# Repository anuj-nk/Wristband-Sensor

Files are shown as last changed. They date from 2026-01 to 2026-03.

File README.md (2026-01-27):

# ThrowSense  
*A wearable system that measures throw speed and estimates throw distance, visualized through a physical stepper-motor gauge and an OLED display.*

---

## Project Overview

ThrowSense is a two-device interactive system consisting of a wearable sensing unit and a handheld or desk-mounted display unit. The wearable tracks the motion of a throw using inertial sensors and computes an estimated throw speed and distance. The display device presents this information using a physical needle gauge driven by a stepper motor, along with an OLED screen for numeric readouts and mode selection.

The system is designed to provide intuitive, glanceable feedback for different throwing contexts (e.g., football, baseball), emphasizing physical interaction and real-world sensing over screen-only visualization.

### General Physical Sketch


---

## Sensing Device — Wearable Motion Tracker

### Device Overview

The sensing device is a wrist- or forearm-mounted wearable that captures high-frequency motion data during a throwing action. It detects when a throw occurs, estimates release velocity, and performs lightweight DSP and physics-based calculations before transmitting results to the display device.

### Hardware Components

- **Processor:** ESP32-C3
- **IMU Sensor:** MPU-6050  
  - 3-axis accelerometer  
  - 3-axis gyroscope  
- **Power:**  
  - 3.7V LiPo battery  

### Part Numbers

- ESP32-C3  
- MPU-6050

### How It Works

1. The MPU-6050 continuously samples acceleration and angular velocity.
2. Motion data is filtered and analyzed in real time to detect a throwing event.
3. Peak angular velocity and acceleration are extracted during the throw.
4. Release speed is estimated from IMU data.
5. A simplified physics-based model estimates throw distance based on:
   - selected object type (e.g., football, baseball)
   - assumed release angle
   - object-specific parameters (mass, drag heuristic).
6. Final computed values are transmitted to the display device.

### Sensor Device Sketch


---

## Display Device — Physical Gauge + OLED Interface

### Device Overview

The display device is a handheld or desk-mounted physical interface that presents throw data in both analog and digital forms. A stepper-motor-driven needle provides an immediate visual indication of throw speed, while an OLED display shows numeric values and the selected throw mode. A button allows the user to cycle through object types before throwing.

### Hardware Components

- **Processor:** ESP32-C3
- **Stepper Motor:** 28BYJ-48
- **Stepper Driver:** ULN2003
- **Display:** 0.96" I2C OLED (SSD1306)
- **User Input:** Tactile push button
- **Indicator:** Status LED
- **Power:** Wall power or battery (TBD)

### Part Numbers

- ESP32-C3  
- 28BYJ-48 Stepper Motor  
- ULN2003 Driver Board  
- SSD1306 OLED Display  

### How It Works

1. The display device receives processed throw data from the sensing device.
2. The stepper motor rotates the needle to a mapped angle corresponding to throw speed.
3. The OLED displays:
   - selected throw mode (e.g., football, baseball)
   - measured throw speed
   - estimated throw distance
4. The user presses a button to cycle through throw modes.
5. Mode changes are sent back to the sensing device to update calculation parameters.
6. The status LED indicates system state:
   - **Ready:** system prepared to detect a throw  
   - **Throwing:** motion detected  
   - **Processing:** calculations in progress  

### Display Device Sketch


---

## Device Communication & System Architecture

### Device Communication

- **Communication medium:** To be determined (wired or wireless)
- **Topology:** Sensing device → Display device
- The sensing device performs all DSP and physics calculations.
- The display device focuses on visualization and user interaction.

### System Diagram — High-Level Communication
SystemArchitecture

### System Diagram — Data Flow
514-Schematic_page-0001

**Data Flow Explanation:**

1. Raw IMU data is captured on the sensing device.
2. DSP techniques (filtering, thresholding, peak detection) identify a throw.
3. A physics-based model estimates speed and distance.
4. Final metrics are transmitted to the display device.
5. The display device maps speed to motor position and updates the OLED and LED indicators.

## Datasheets

All datasheets are included in the `/datasheets` directory, including:

- ESP32-C3 datasheet  
- MPU-6050 datasheet  
- 28BYJ-48 stepper motor datasheet  
- ULN2003 driver datasheet  
- SSD1306 OLED datasheet

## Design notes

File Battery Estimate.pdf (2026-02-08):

System Parameters (defined by hardware) | Profiles (usage of each component mode - defined by software and usage)
form the datasheets
"off" | "sensing" | "interactive"
Processor
Active | 76 mW | 0% | 1% | 20%

This is for my Sensing Device which is using battery and not my Display which is not using battery
Idle | 53 mW | 0% | 4% | 10%
Deep Sleep | 0 mW | 100% | 95% | 70%

Values are rounded, but I
changed template values
although it still shows 0

LED

On | 0 mW | 0% | 0% | 0%

No LED in sensing device, based on this battery analysis maybe I can include one

Sensor
On | 13 mW | 0% | 0% | 100%
Idle | 2 mW | 0% | 100% | 0%
Off | 0 mW | 100% | 0% | 0%

Display
On | 0 mW | 0% | 0% | 0%
Off (leakage) | 0 mW | 0% | 0% | 0% No Display for Sensing Device

Radio

Data Rate | 13,000 bps | 0% | 0% | 0%

There is a DPU on the MPU6050 which does all the calculations

and would reduce amount of
dataneeded to be sent, but for
now assuming you send all data
to other microcontroller | Total power in profile (mw) | Maximum Time
Standby Power | 1 mW | 0% | 100% | 95% | "off" | 0.4455 mW | 1931.0 hours
TX Power | 65 mW | 0% | 0% | 3% | "sensing" | 5.99155 mW | 143.6 hours
RX Power | 40 mW | 0% | 0% | 2% | "interactive" | 37.3303 mW | 23.0 hours
14 | 9 | 1 hours/day typical usage | Effective Battery Capacity
Battery | | | | | | 860.25 mW*h
Capacity | 250 mAh
Nominal Voltage | 4 V | | | | Days of Use | 8.82 days
Regulator Efficiency | 93% | | | | Hours of Use | 211.77 hours

REFLECTIONS : WHAT DID YOU LEARN FROM ANALYZING YOUR POWER. TALK ABOUT SOME POTENTIAL TRADEOFFS.
Based on the power analysis, I determined the days of use metric by modeling a typical day across three usage profiles: off, sensing, and interactive, and weighting each by the expected hours per day. This approach captures realistic behavior rather than relying on worst case or peak power scenarios. Using this model, a 210 mAh battery provides approximately 7.4 days of operation, while even a much smaller 50 mAh battery still supports about 1.7 days of typical use.

Given these results, an optimal battery size for the wristband is likely in the 200 to 300 mAh range. This size provides ample margin for variability in usage, battery aging, and inefficiencies, while remaining small and comfortable for a wearable form factor. The analysis also shows that the system could function for a full day with a significantly smaller battery if needed.

Several tradeoffs could further improve the user experience. From a software perspective, minimizing radio usage by computing velocity on-device and transmitting only compact result packets keeps power consumption low without reducing functionality. From a hardware perspective, aggressively using sensor low power modes and processor sleep states improves battery life at the cost of slightly increased latency and implementation effort. Increasing responsiveness or streaming more data would improve immediacy and fidelity but would require higher power draw, a larger battery, or additional development complexity.

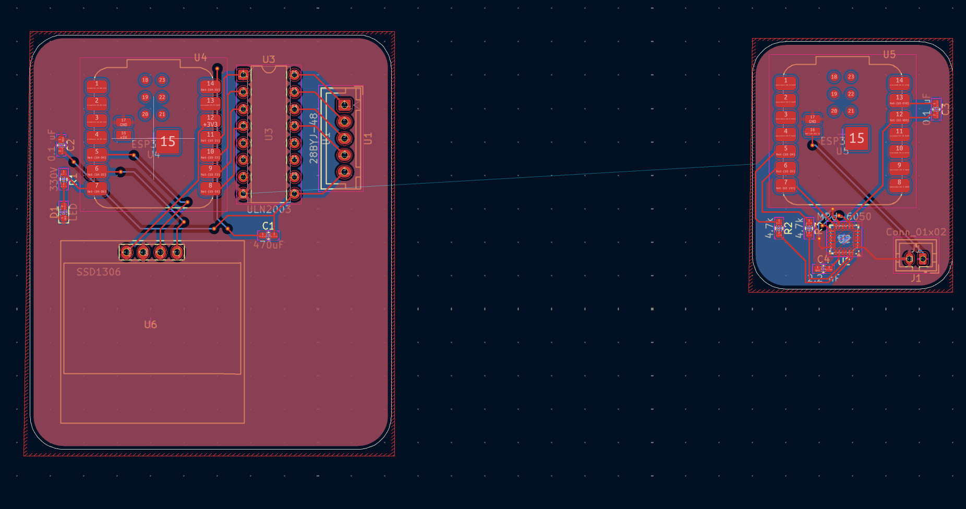
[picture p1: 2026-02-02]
TECHIN514_w26_project_PCB/514-Schematic-FinalProject/Screenshot 2026-02-02 at 3.05.42 PM.png

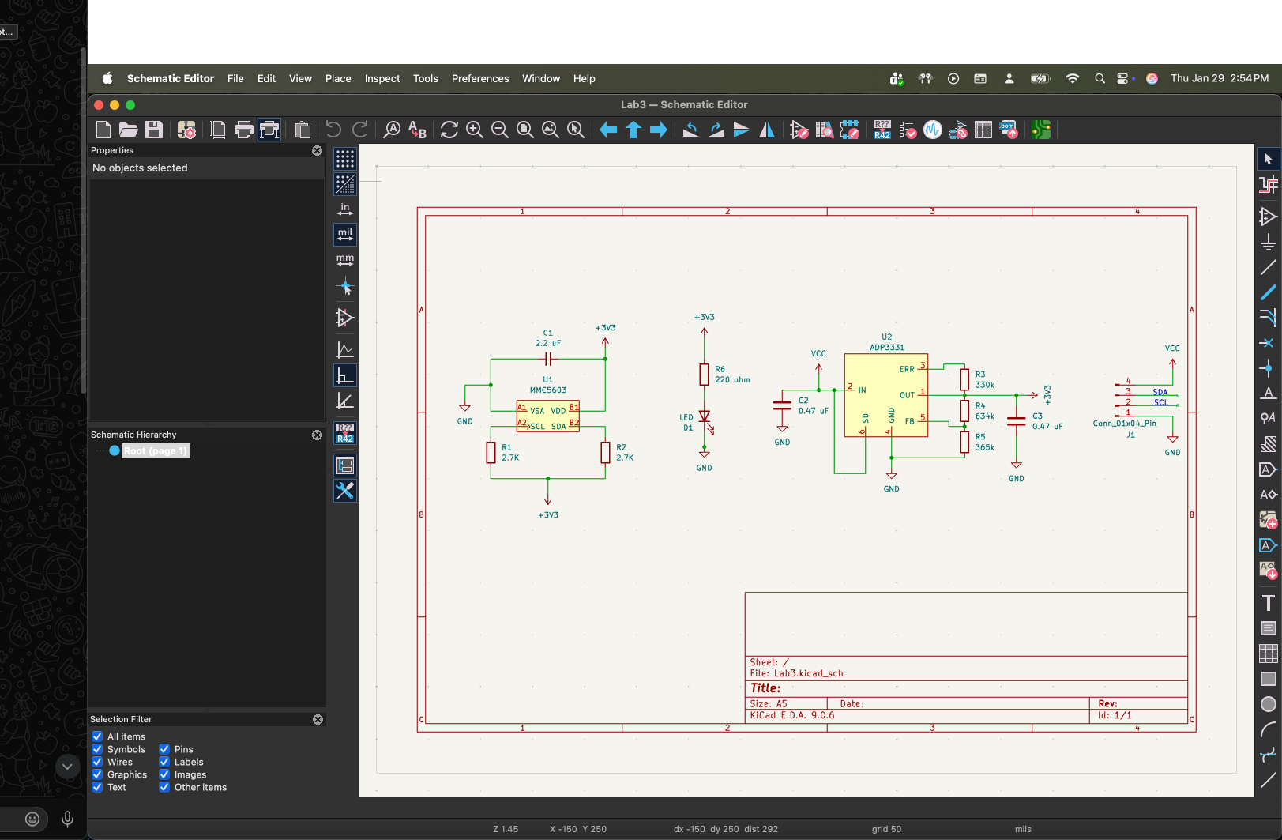
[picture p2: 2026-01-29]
TECHIN514_w26_project_PCB/Lab3/SchematicDiagram.png

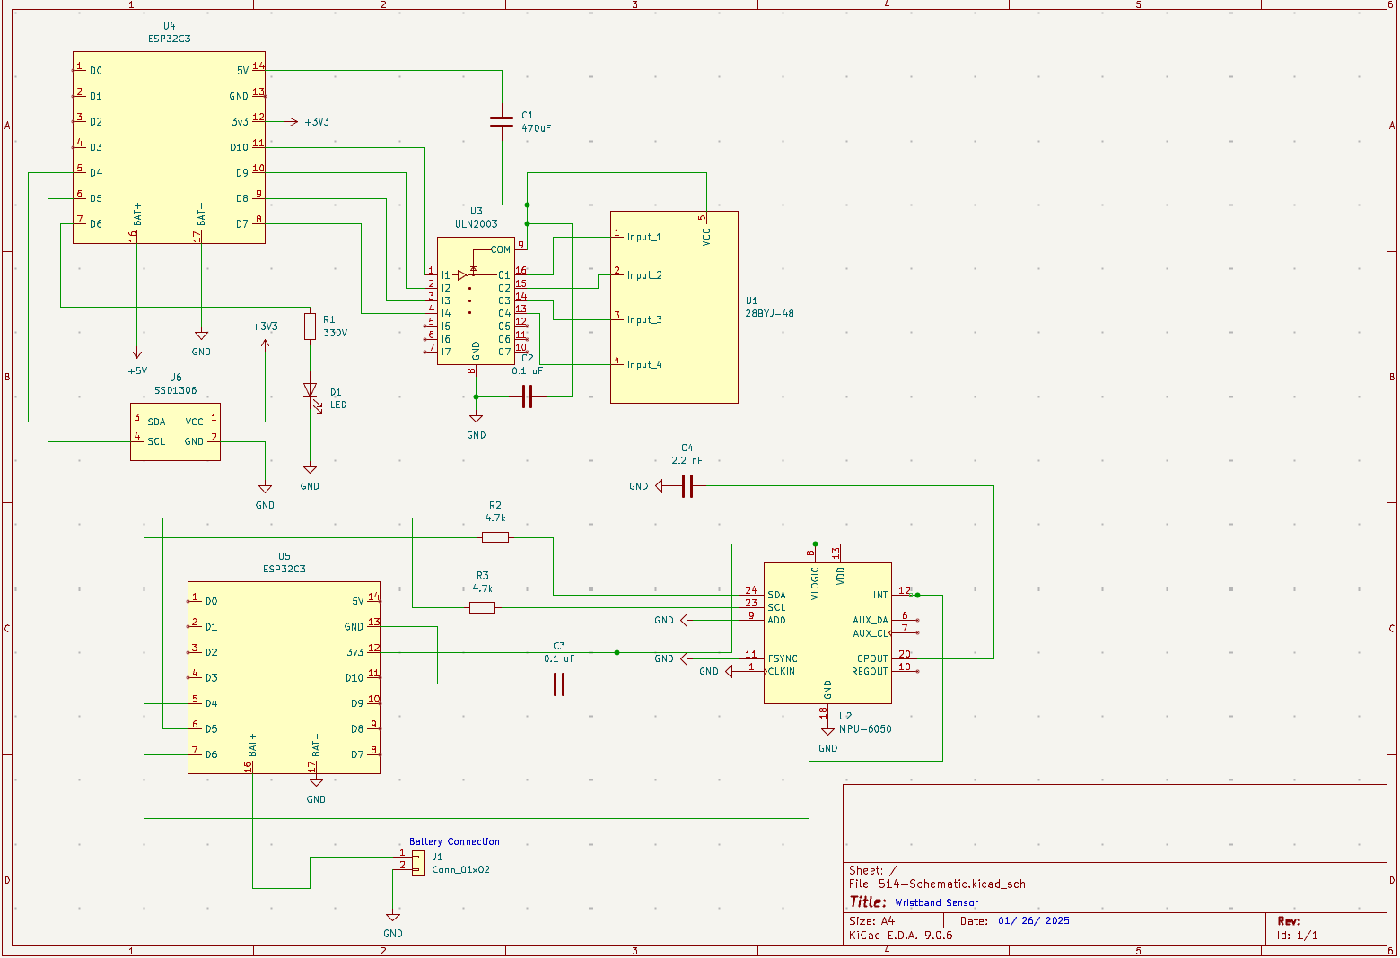
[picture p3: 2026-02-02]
TECHIN514_w26_project_PCB/514-Schematic-FinalProject/Screenshot 2026-02-02 at 3.06.13 PM.png

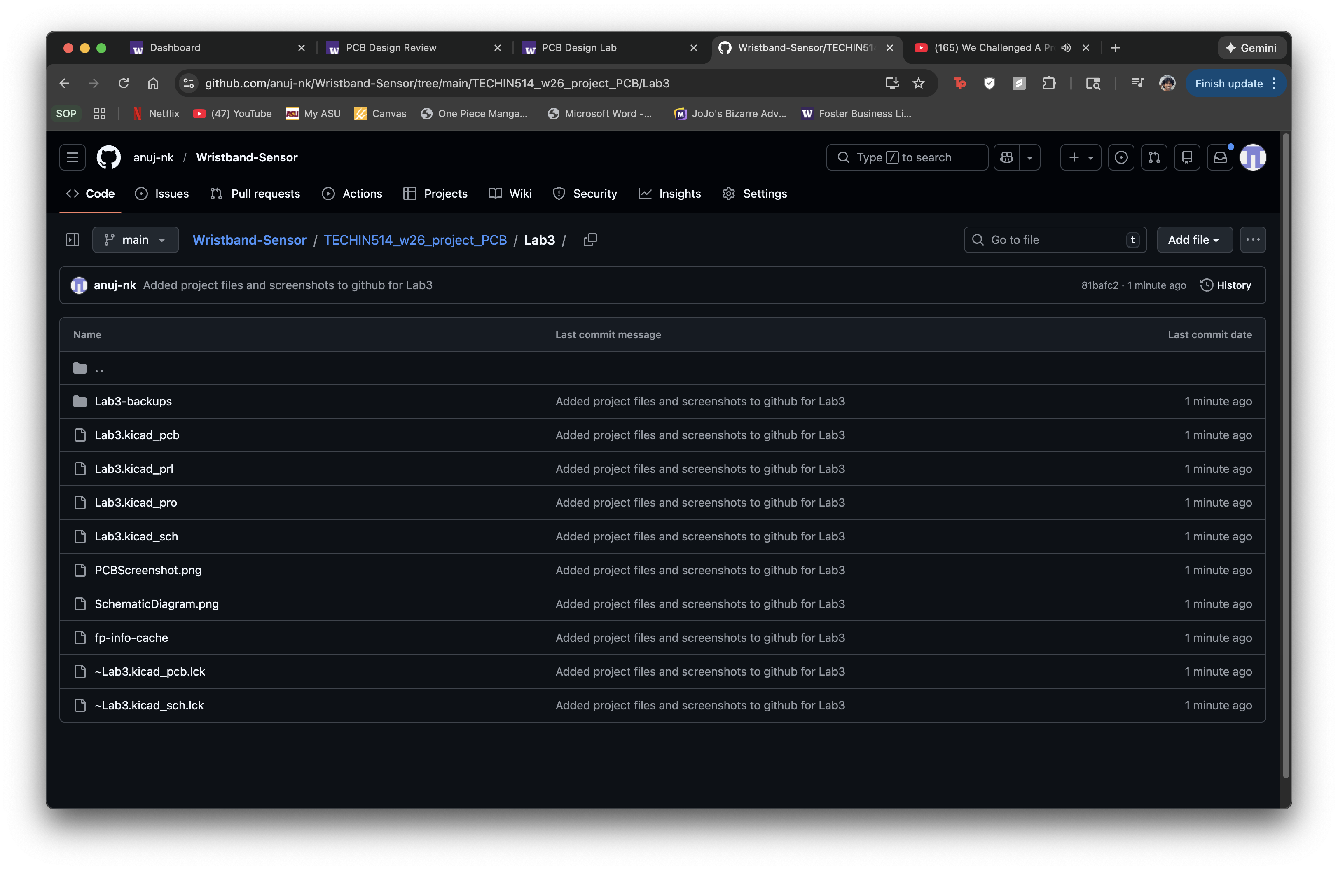
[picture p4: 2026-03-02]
TECHIN514_w26_project_PCB/Lab3/Screenshot 2026-01-29 at 2.56.57 PM.png

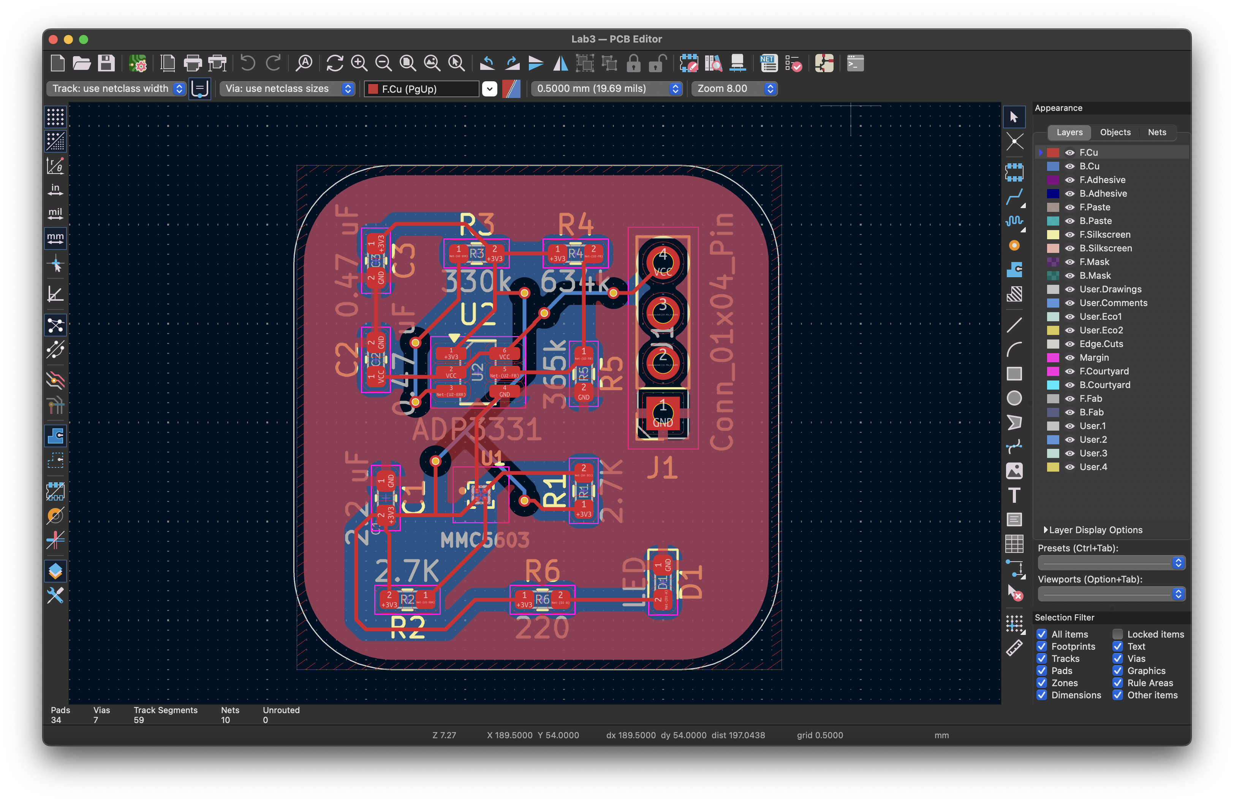
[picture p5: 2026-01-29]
TECHIN514_w26_project_PCB/Lab3/PCBScreenshot.png

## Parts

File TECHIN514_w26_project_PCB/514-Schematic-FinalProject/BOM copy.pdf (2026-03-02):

### BOM

Reference | Qty | Value | DNP | Exclude from BOM | Exclude from Board | Footprint | Datasheet
C1 | 1 | 470uF | | | | Capacitor_SMD:C_0603_1608Metric_Pad1.08x0.95mm_HandSolder | ~
C2,C3 | 2 | 0.1 uF | | | | Capacitor_SMD:C_0603_1608Metric_Pad1.08x0.95mm_HandSolder | ~
C4 | 1 | 2.2 nF | | | | Capacitor_SMD:C_0603_1608Metric_Pad1.08x0.95mm_HandSolder | ~
D1 | 1 | LED - Red | | | | LED_SMD:LED_0603_1608Metric_Pad1.05x0.95mm_HandSolder | ~
J1 | 1 | Conn_01x02 | | | | Connector_JST:JST_PH_B2B-PH-K_1x02_P2.00mm_Vertical | ~
R1 | 1 | 330Ω | | | | Resistor_SMD:R_0603_1608Metric_Pad0.98x0.95mm_HandSolder | ~
R2,R3 | 2 | 4.7k | | | | Resistor_SMD:R_0603_1608Metric_Pad0.98x0.95mm_HandSolder | ~
U1 | 1 | 28BYJ-48 | Connector_JST:JST_XH_B5B-XH-A_1x05_P2.50mm_Vertical | https://www.mouser.com/datasheet/2/758/stepd-01-data-sheet-1143075.pdf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
U2 | 1 | MPU-6050 | Sensor_Motion:InvenSense_QFN-24_4x4mm_P0.5mm | https://invensense.tdk.com/wp-content/uploads/2015/02/MPU-6000-Datasheet1.pdf
U3 | 1 | ULN2003 | Package_DIP:DIP-16_W7.62mm | http://www.ti.com/lit/ds/symlink/uln2003a.pdf
U4,U5 | 2 | ESP32C3 | RF_Module:MCU_Seeed_ESP32C3 | https://documentation.espressif.com/esp32-c3_datasheet_en.pdf
U6 | 1 | SSD1306 | Footprints:128x64OLED | https://cdn-shop.adafruit.com/datasheets/SSD1306.pdf

1

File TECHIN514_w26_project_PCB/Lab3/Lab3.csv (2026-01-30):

Reference | Qty | Value | DNP | Exclude from BOM | Exclude from Board | Footprint | Datasheet
C1 | 1 | 2.2 uF |  |  |  | Capacitor_SMD:C_0603_1608Metric_Pad1.08x0.95mm_HandSolder | ~
C2,C3 | 2 | 0.47 uF |  |  |  | Capacitor_SMD:C_0603_1608Metric_Pad1.08x0.95mm_HandSolder | ~
D1 | 1 | LED |  |  |  | LED_SMD:LED_0603_1608Metric_Pad1.05x0.95mm_HandSolder | ~
J1 | 1 | Conn_01x04_Pin |  |  |  | Connector_PinSocket_2.54mm:PinSocket_1x04_P2.54mm_Vertical | ~
R1,R2 | 2 | 2.7K |  |  |  | Resistor_SMD:R_0603_1608Metric_Pad0.98x0.95mm_HandSolder | ~
R3 | 1 | 330k |  |  |  | Resistor_SMD:R_0603_1608Metric_Pad0.98x0.95mm_HandSolder | ~
R4 | 1 | 634k |  |  |  | Resistor_SMD:R_0603_1608Metric_Pad0.98x0.95mm_HandSolder | ~
R5 | 1 | 365k |  |  |  | Resistor_SMD:R_0603_1608Metric_Pad0.98x0.95mm_HandSolder | ~
R6 | 1 | 220 ohm |  |  |  | Resistor_SMD:R_0603_1608Metric_Pad0.98x0.95mm_HandSolder | ~
U1 | 1 | MMC5603 |  |  |  | MMC5603NJ:XDCR_MMC5603NJ
U2 | 1 | ADP3331 |  |  |  | Package_TO_SOT_SMD:SOT-23-6_Handsoldering

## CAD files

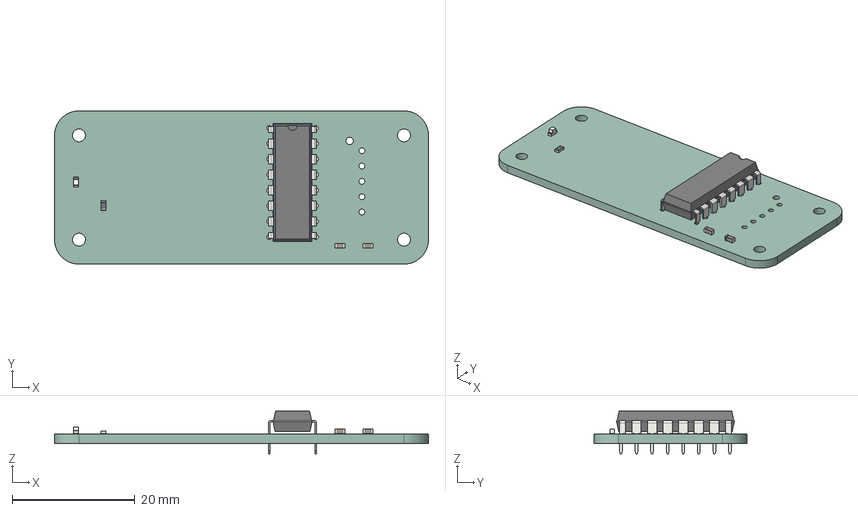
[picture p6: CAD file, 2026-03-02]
TECHIN514_w26_project_PCB/514-Schematic-FinalProject/514-Schematic-D.step
61.0 x 25.0 x 6.98 mm
LED_0603_1608Metric
R_0603_1608Metric
C_0603_1608Metric x 2
DIP-16_W7.62mm
514-Schematic-D_PCB

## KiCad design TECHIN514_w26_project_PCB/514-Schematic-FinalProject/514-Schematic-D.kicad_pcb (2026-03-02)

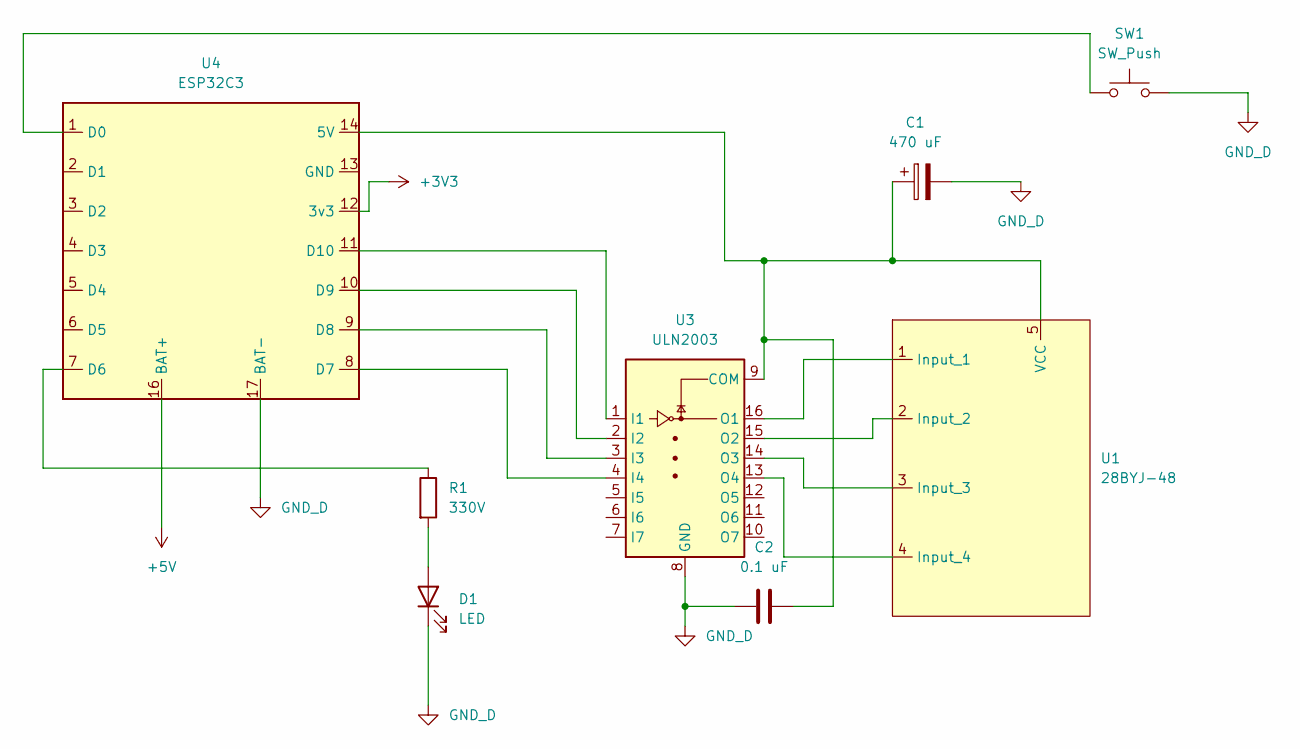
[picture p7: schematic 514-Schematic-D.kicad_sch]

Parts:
C1: 470 uF; C_0603_1608Metric_Pad1.08x0.95mm_HandSolder
C2: 0.1 uF; C_0603_1608Metric_Pad1.08x0.95mm_HandSolder
D1: LED; LED_0603_1608Metric_Pad1.05x0.95mm_HandSolder
R1: 330V; R_0603_1608Metric_Pad0.98x0.95mm_HandSolder
SW1: SW_Push; SW_PUSH_6mm
U1: 28BYJ-48; JST_XH_B5B-XH-AM_1x05_P2.50mm_Vertical
U3: ULN2003; DIP-16_W7.62mm
U4: ESP32C3; MCU_Seeed_ESP32C3

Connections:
+3V3: U4.12 (3v3)
+5V: U4.16 (BAT+)
GND_D: C1.2, C2.1, D1.1 (K), SW1.2, U3.8 (GND), U4.17 (BAT-)
unnamed: D1.2 (A), R1.2
unnamed: U1.1 (Input_1), U3.16 (O1)
unnamed: U1.2 (Input_2), U3.15 (O2)
unnamed: U1.3 (Input_3), U3.14 (O3)
unnamed: U1.4 (Input_4), U3.13 (O4)
unnamed: C1.1, C2.2, U1.5 (VCC), U3.9 (COM), U4.14 (5V)
unnamed: U3.1 (I1), U4.11 (D10)
unnamed: U3.2 (I2), U4.10 (D9)
unnamed: U3.3 (I3), U4.9 (D8)
unnamed: U3.4 (I4), U4.8 (D7)
unnamed: SW1.1, U4.1 (D0)
unnamed: R1.1, U4.7 (D6)

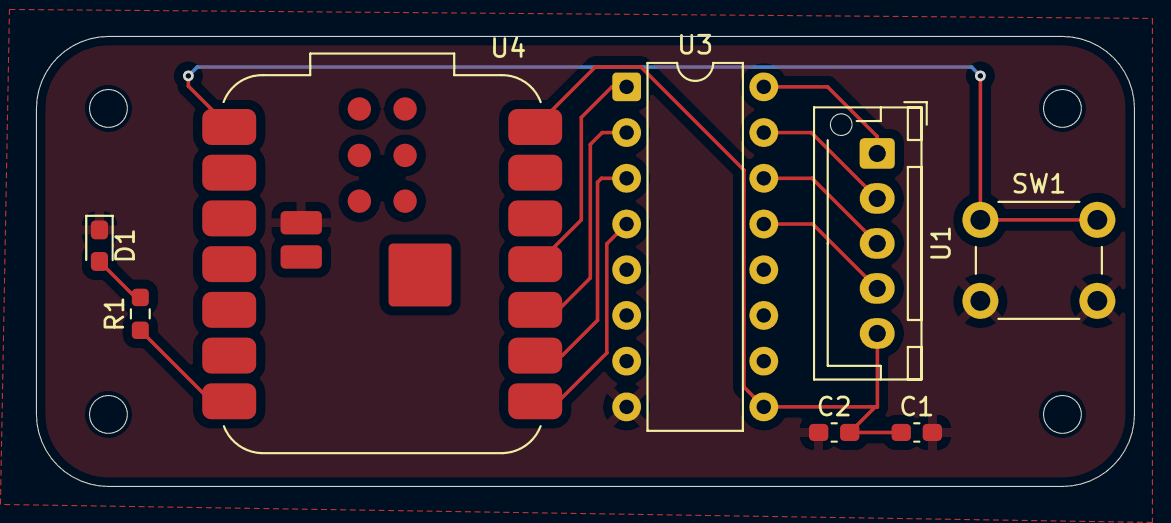
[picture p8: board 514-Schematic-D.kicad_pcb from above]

Board: 2 copper layers, 61.0 x 25.0 mm, 8 parts (0 on the bottom side), 13 nets.

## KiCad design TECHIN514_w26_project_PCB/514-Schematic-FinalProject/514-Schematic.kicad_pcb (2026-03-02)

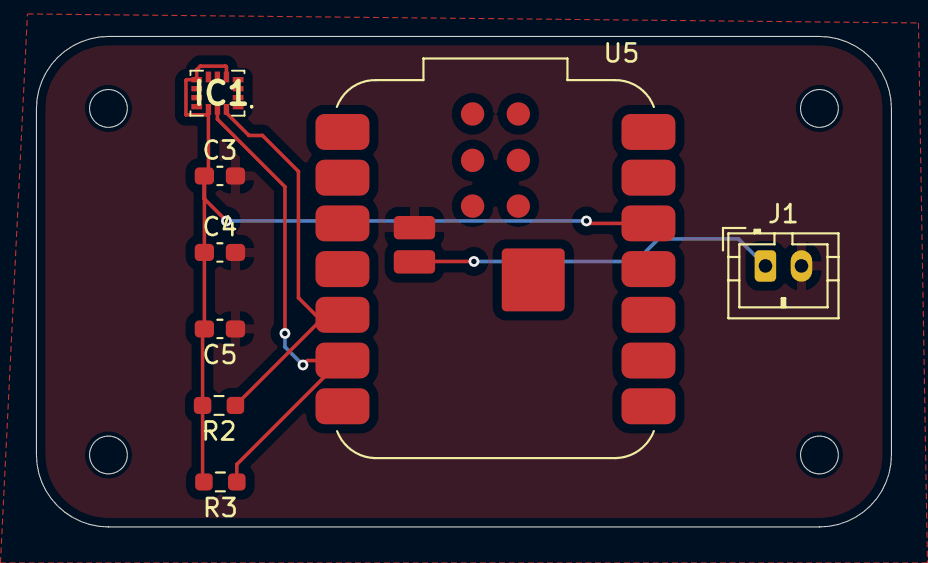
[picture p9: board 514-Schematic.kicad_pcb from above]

Board: 2 copper layers, 47.5 x 27.2 mm, 8 parts (0 on the bottom side), 5 nets.

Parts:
C3: 0.1 uF; C_0603_1608Metric_Pad1.08x0.95mm_HandSolder
C4: 2.2 uF; C_0603_1608Metric_Pad1.08x0.95mm_HandSolder
C5: 10 nF; C_0603_1608Metric_Pad1.08x0.95mm_HandSolder
IC1: ICM-42670-P; ICM42670P
J1: Conn_01x02; JST_PH_B2B-PH-K_1x02_P2.00mm_Vertical
R2, R3: 10 kΩ; R_0603_1608Metric_Pad0.98x0.95mm_HandSolder
U5: ESP32C3; MCU_Seeed_ESP32C3

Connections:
GND: C3.2, C4.2, C5.1, IC1.1 (AP_SDO_/_AP_AD0), IC1.6 (GND), IC1.7 (FSYNC), J1.2, U5.17 (BAT-)
unnamed: C3.1, C4.1, C5.2, IC1.5 (VDDIO), IC1.8 (VDD), IC1.12 (AP_CS), R2.2, R3.2, U5.12 (3v3)
unnamed: IC1.13 (AP_SCL_/_AP_SCLK), R3.1, U5.6 (D5)
unnamed: IC1.14 (AP_SDA_/_AP_SDIO_/_AP_SDI), R2.1, U5.5 (D4)
unnamed: J1.1, U5.16 (BAT+)

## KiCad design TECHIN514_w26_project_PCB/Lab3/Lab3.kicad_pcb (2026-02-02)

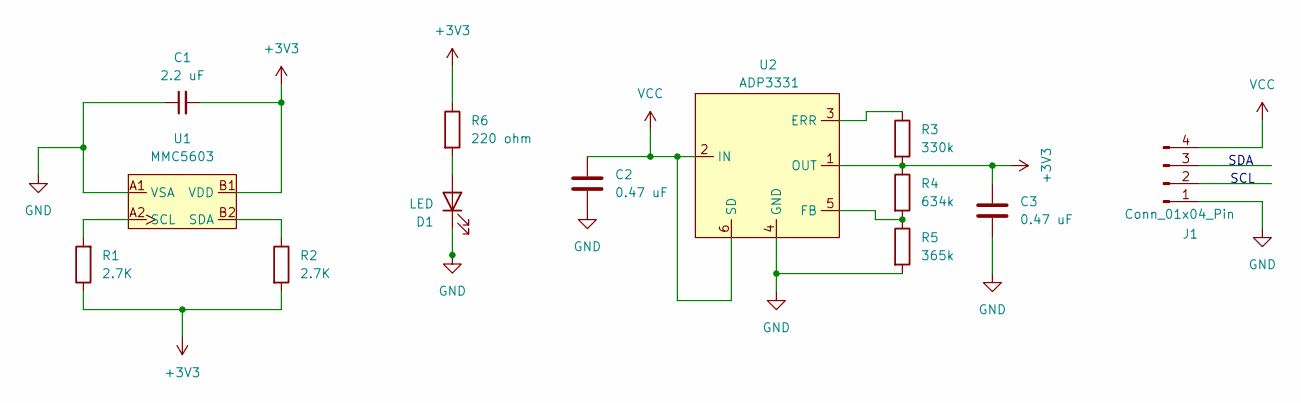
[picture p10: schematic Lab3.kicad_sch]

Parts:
C1: 2.2 uF; C_0603_1608Metric_Pad1.08x0.95mm_HandSolder
C2, C3: 0.47 uF; C_0603_1608Metric_Pad1.08x0.95mm_HandSolder
D1: LED; LED_0603_1608Metric_Pad1.05x0.95mm_HandSolder
J1: Conn_01x04_Pin; PinSocket_1x04_P2.54mm_Vertical
R1, R2: 2.7K; R_0603_1608Metric_Pad0.98x0.95mm_HandSolder
R3: 330k; R_0603_1608Metric_Pad0.98x0.95mm_HandSolder
R4: 634k; R_0603_1608Metric_Pad0.98x0.95mm_HandSolder
R5: 365k; R_0603_1608Metric_Pad0.98x0.95mm_HandSolder
R6: 220 ohm; R_0603_1608Metric_Pad0.98x0.95mm_HandSolder
U1: MMC5603; XDCR_MMC5603NJ
U2: ADP3331; SOT-23-6_Handsoldering

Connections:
+3V3: C1.2, C3.1, R1.1, R2.2, R3.2, R4.1, R6.1, U1.B1 (VDD), U2.1 (OUT)
GND: C1.1, C2.2, C3.2, D1.1 (K), J1.1, R5.2, U1.A1 (VSA), U2.4 (GND)
unnamed: D1.2 (A), R6.2
unnamed: R1.2, U1.A2 (SCL)
unnamed: R2.1, U1.B2 (SDA)
unnamed: R3.1, U2.3 (ERR)
unnamed: R4.2, R5.1, U2.5 (FB)
VCC: C2.1, J1.4, U2.2 (IN), U2.6 (SD)

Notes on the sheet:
SDA
SCL

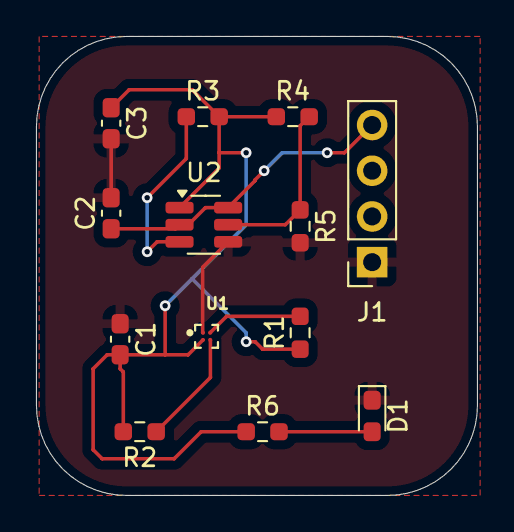
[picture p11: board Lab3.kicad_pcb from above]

Board: 2 copper layers, 24.5 x 25.5 mm, 13 parts (0 on the bottom side), 8 nets.

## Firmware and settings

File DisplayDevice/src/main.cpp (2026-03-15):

#include <Arduino.h>
#include <BLEDevice.h>
#include <BLEServer.h>
#include <BLEUtils.h>
#include <BLE2902.h>

// -------------------------
// Pin definitions
// -------------------------
const int IN1 = D2;
const int IN2 = D1;
const int IN3 = D0;
const int IN4 = D7;

const int BUTTON_PIN = D4;
const int LED_PIN    = D6;

// -------------------------
// BLE UUIDs
// -------------------------
// Keep these the same on the sender/client side.
#define DEVICE_NAME         "ThrowSenseDisplay"
#define SERVICE_UUID        "6f1c0001-4b1f-4f6c-9c79-1234567890ab"
#define CHARACTERISTIC_UUID "6f1c0002-4b1f-4f6c-9c79-1234567890ab"

// -------------------------
// BLE globals
// -------------------------
BLEServer* pServer = NULL;
BLECharacteristic* pCharacteristic = NULL;
bool deviceConnected = false;
bool oldDeviceConnected = false;

// When BLE data arrives, loop() will process it
bool newMphPending = false;
float pendingMph = 0.0f;

// -------------------------
// Stepper sequence
// -------------------------
const uint8_t seq[4][4] = {
  {1, 1, 0, 0},
  {0, 1, 1, 0},
  {0, 0, 1, 1},
  {1, 0, 0, 1}
};

// -------------------------
// Calibration settings
// -------------------------
const int NUM_ANCHORS = 9;
const int anchorMPH[NUM_ANCHORS] = {0, 10, 20, 30, 40, 50, 60, 70, 80};

long anchorSteps[NUM_ANCHORS] = {0, -33, -76, -114, -157, -204, -251, -279, -314};
bool anchorSet[NUM_ANCHORS]   = {true, true, true, true, true, true, true, true, true};

// -------------------------
// Stepper state
// -------------------------
long currentStep = 0;
int currentSeqIdx = 0;

// -------------------------
// LED/UI state
// -------------------------
bool displayedValueReady = false;
bool motorMoving = false;
bool ledState = false;
unsigned long lastBlinkMs = 0;
unsigned long rxBlinkUntilMs = 0;
float displayedMph = 0.0f;         // what the needle is currently showing
const float MIN_VALID_MPH = 15.0f; // ignore values below this
const float MPH_HYSTERESIS = 3.0f; // require this much increase before moving

// -------------------------
// Button state
// -------------------------
bool lastButtonReading = HIGH;
bool buttonPressed = false;
unsigned long buttonPressStart = 0;
unsigned long lastDebounceTime = 0;
const unsigned long debounceMs = 30;
const unsigned long longPressMs = 1200;

// -------------------------
// BLE callbacks
// -------------------------
class MyServerCallbacks : public BLEServerCallbacks {
  void onConnect(BLEServer* pServer) override {
    deviceConnected = true;
    Serial.println("BLE client connected");
  }

  void onDisconnect(BLEServer* pServer) override {
    deviceConnected = false;
    Serial.println("BLE client disconnected");
  }
};

class MyCharacteristicCallbacks : public BLECharacteristicCallbacks {
  void onWrite(BLECharacteristic* pCharacteristic) override {
    std::string rxValue = pCharacteristic->getValue();

    if (rxValue.length() == 0) return;

    String s = String(rxValue.c_str());
    s.trim();

    float mph = s.toFloat();

    Serial.print("BLE write received MPH: ");
    Serial.println(mph, 1);

    pendingMph = mph;
    newMphPending = true;
    rxBlinkUntilMs = millis() + 300;
  }
};

// -------------------------
// Stepper helpers
// -------------------------
void setStep(int a, int b, int c, int d) {
  digitalWrite(IN1, a);
  digitalWrite(IN2, b);
  digitalWrite(IN3, c);
  digitalWrite(IN4, d);
}

void applyStep(int idx) {
  idx = (idx + 4) % 4;
  setStep(seq[idx][0], seq[idx][1], seq[idx][2], seq[idx][3]);
}

void allOff() {
  setStep(0, 0, 0, 0);
}

// -------------------------
// LED helpers
// -------------------------
void ledOff() {
  digitalWrite(LED_PIN, LOW);
}

void ledOn() {
  digitalWrite(LED_PIN, HIGH);
}

void blinkLED(unsigned long intervalMs = 100) {
  unsigned long now = millis();
  if (now - lastBlinkMs >= intervalMs) {
    lastBlinkMs = now;
    ledState = !ledState;
    digitalWrite(LED_PIN, ledState ? HIGH : LOW);
  }
}

// -------------------------
// Calibration helpers
// -------------------------
bool allAnchorsSet() {
  for (int i = 0; i < NUM_ANCHORS; i++) {
    if (!anchorSet[i]) return false;
  }
  return true;
}

void printCalibration() {
  Serial.println("Calibration table:");
  for (int i = 0; i < NUM_ANCHORS; i++) {
    Serial.print("  ");
    Serial.print(anchorMPH[i]);
    Serial.print(" mph -> ");
    Serial.println(anchorSteps[i]);
  }
}

// -------------------------
// Stepper motion
// -------------------------
void stepMotor(int dir, int delayMs = 8) {
  currentSeqIdx = (currentSeqIdx + dir + 4) % 4;
  applyStep(currentSeqIdx);
  delay(delayMs);
  currentStep += dir;
}

void moveRelative(long deltaSteps, int delayMs = 8) {
  if (deltaSteps == 0) {
    motorMoving = false;
    displayedValueReady = true;
    ledOn();
    return;
  }

  motorMoving = true;
  displayedValueReady = false;

  long stepsToMove = labs(deltaSteps);
  int dir = (deltaSteps > 0) ? +1 : -1;

  for (long i = 0; i < stepsToMove; i++) {
    blinkLED(60);
    stepMotor(dir, delayMs);
  }

  allOff();
  motorMoving = false;
  displayedValueReady = true;
  ledOn();
}

void moveToStep(long targetStep, int delayMs = 8) {
  long delta = targetStep - currentStep;
  Serial.print("Moving from step ");
  Serial.print(currentStep);
  Serial.print(" to ");
  Serial.println(targetStep);
  moveRelative(delta, delayMs);
}

// -------------------------
// MPH interpolation
// -------------------------
bool getStepForMPH(float mph, long &targetStep) {
  if (!allAnchorsSet()) return false;

  if (mph <= anchorMPH[0]) {
    targetStep = anchorSteps[0];
    return true;
  }

  if (mph >= anchorMPH[NUM_ANCHORS - 1]) {
    targetStep = anchorSteps[NUM_ANCHORS - 1];
    return true;
  }

  for (int i = 0; i < NUM_ANCHORS - 1; i++) {
    if (mph >= anchorMPH[i] && mph <= anchorMPH[i + 1]) {
      float mph0 = anchorMPH[i];
      float mph1 = anchorMPH[i + 1];
      long s0 = anchorSteps[i];
      long s1 = anchorSteps[i + 1];

      float t = (mph - mph0) / (mph1 - mph0);
      targetStep = lround(s0 + t * (s1 - s0));
      return true;
    }
  }

  return false;
}

void goToMPH(float mph) {
  long targetStep;
  if (!getStepForMPH(mph, targetStep)) {
    Serial.println("Cannot move to MPH: calibration incomplete.");
    return;
  }

  Serial.print("MPH ");
  Serial.print(mph, 1);
  Serial.print(" -> target step ");
  Serial.println(targetStep);

  moveToStep(targetStep, 8);
  displayedMph = mph;
}

void handleIncomingMph(float mph) {
  Serial.print("Detected MPH from wristband: ");
  Serial.println(mph, 1);

  // Ignore tiny/noisy values
  if (mph < MIN_VALID_MPH) {
    Serial.println("Ignored: below minimum threshold.");
    return;
  }

  // Ignore very small changes to avoid jitter
  float diff = fabs(mph - displayedMph);
  if (diff < MPH_HYSTERESIS) {
    Serial.print("Ignored: change too small. Current displayed MPH = ");
    Serial.print(displayedMph, 1);
    Serial.print(", diff = ");
    Serial.println(diff, 1);
    return;
  }

  Serial.print("Accepted MPH: ");
  Serial.println(mph, 1);

  goToMPH(mph);
}
// -------------------------
// Button handling
// -------------------------
void handleButton() {
  bool reading = digitalRead(BUTTON_PIN);

  if (reading != lastButtonReading) {
    lastDebounceTime = millis();
  }

  if ((millis() - lastDebounceTime) > debounceMs) {
    if (reading == LOW && !buttonPressed) {
      buttonPressed = true;
      buttonPressStart = millis();
    }

    if (reading == HIGH && buttonPressed) {
      unsigned long pressDuration = millis() - buttonPressStart;
      buttonPressed = false;

      if (pressDuration >= longPressMs) {
        Serial.println("Long press: moving to 0 MPH and resetting logical zero.");
        goToMPH(0);
        currentStep = 0;
        displayedMph = 0.0f;
      } else {
        currentStep = 0;
        displayedMph = 0.0f;
        displayedValueReady = true;
        ledOn();
        Serial.println("Short press: logical zero and displayed MPH reset.");
      }
    }
  }

  lastButtonReading = reading;
}

// -------------------------
// Serial command handling
// -------------------------
void printHelp() {
  Serial.println("\nCommands:");
  Serial.println("  f <steps>     move forward");
  Serial.println("  b <steps>     move backward");
  Serial.println("  zero          set logical zero");
  Serial.println("  go <mph>      move needle to mph");
  Serial.println("  ble <mph>     simulate BLE write");
  Serial.println("  print         print calibration table");
  Serial.println("  help          show commands");
}

void handleSerial() {
  if (!Serial.available()) return;

  String cmd = Serial.readStringUntil('\n');
  cmd.trim();

  if (cmd.length() == 0) return;

  if (cmd.equalsIgnoreCase("help")) {
    printHelp();
    return;
  }

  if (cmd.equalsIgnoreCase("zero")) {
    currentStep = 0;
    displayedValueReady = true;
    ledOn();
    Serial.println("Logical zero set.");
    return;
  }

  if (cmd.equalsIgnoreCase("print")) {
    printCalibration();
    return;
  }

  if (cmd.startsWith("f ")) {
    int steps = cmd.substring(2).toInt();
    Serial.print("Forward ");
    Serial.println(steps);
    moveRelative(steps, 8);
    return;
  }

  if (cmd.startsWith("b ")) {
    int steps = cmd.substring(2).toInt();
    Serial.print("Backward ");
    Serial.println(steps);
    moveRelative(-steps, 8);
    return;
  }

  if (cmd.startsWith("go ")) {
    float mph = cmd.substring(3).toFloat();
    goToMPH(mph);
    return;
  }

  if (cmd.startsWith("ble ")) {
    float mph = cmd.substring(4).toFloat();
    Serial.print("Simulated BLE MPH: ");
    Serial.println(mph, 1);
    pendingMph = mph;
    newMphPending = true;
    rxBlinkUntilMs = millis() + 300;
    return;
  }

  Serial.println("Unknown command.");
  printHelp();
}

// -------------------------
// BLE setup
// -------------------------
void setupBLE() {
  BLEDevice::init(DEVICE_NAME);

  pServer = BLEDevice::createServer();
  pServer->setCallbacks(new MyServerCallbacks());

  BLEService* pService = pServer->createService(SERVICE_UUID);

  pCharacteristic = pService->createCharacteristic(
    CHARACTERISTIC_UUID,
    BLECharacteristic::PROPERTY_READ |
    BLECharacteristic::PROPERTY_WRITE |
    BLECharacteristic::PROPERTY_NOTIFY
  );

  pCharacteristic->addDescriptor(new BLE2902());
  pCharacteristic->setValue("0");
  pCharacteristic->setCallbacks(new MyCharacteristicCallbacks());

  pService->start();

  BLEAdvertising* pAdvertising = BLEDevice::getAdvertising();
  pAdvertising->addServiceUUID(SERVICE_UUID);
  pAdvertising->setScanResponse(true);
  pAdvertising->setMinPreferred(0x06);
  pAdvertising->setMinPreferred(0x12);

  BLEDevice::startAdvertising();

  Serial.println("BLE advertising started.");
  Serial.print("Device name: ");
  Serial.println(DEVICE_NAME);
}

// -------------------------
// LED state machine
// -------------------------
void updateLED() {
  if (motorMoving) {
    blinkLED(60);
    return;
  }

  if (millis() < rxBlinkUntilMs) {
    blinkLED(40);
    return;
  }

  if (displayedValueReady) {
    ledOn();
  } else {
    ledOff();
  }
}

// -------------------------
// Setup / loop
// -------------------------
void setup() {
  Serial.begin(115200);
  delay(1500);

  pinMode(IN1, OUTPUT);
  pinMode(IN2, OUTPUT);
  pinMode(IN3, OUTPUT);
  pinMode(IN4, OUTPUT);

  pinMode(BUTTON_PIN, INPUT_PULLUP);
  pinMode(LED_PIN, OUTPUT);

  allOff();
  ledOff();

  Serial.println("ThrowSense display ready.");
  printCalibration();
  printHelp();

  setupBLE();
}

void loop() {
  handleButton();
  handleSerial();

  if (newMphPending) {
    float mph = pendingMph;
    newMphPending = false;
    handleIncomingMph(mph);
  }

  // reconnect advertising if client disconnects
  if (!deviceConnected && oldDeviceConnected) {
    delay(500);
    pServer->startAdvertising();
    Serial.println("Start advertising");
    oldDeviceConnected = deviceConnected;
  }

  if (deviceConnected && !oldDeviceConnected) {
    oldDeviceConnected = deviceConnected;
  }

  updateLED();
}

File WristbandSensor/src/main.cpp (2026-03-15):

#include <Arduino.h>
#include <Wire.h>
#include <BLEDevice.h>
#include <BLEUtils.h>
#include <BLEScan.h>
#include <BLEAdvertisedDevice.h>
#include <BLEClient.h>

// =====================================================
// MPU-6050 wiring
// =====================================================
const int IMU_SDA = D4;
const int IMU_SCL = D5;
const int IMU_INT = D7;

const uint8_t MPU_ADDR = 0x68;
uint8_t imuAddr = 0;

// =====================================================
// MPU-6050 registers
// =====================================================
const uint8_t REG_WHO_AM_I      = 0x75;
const uint8_t REG_PWR_MGMT_1    = 0x6B;
const uint8_t REG_SMPLRT_DIV    = 0x19;
const uint8_t REG_CONFIG        = 0x1A;
const uint8_t REG_GYRO_CONFIG   = 0x1B;
const uint8_t REG_ACCEL_CONFIG  = 0x1C;
const uint8_t REG_INT_PIN_CFG   = 0x37;
const uint8_t REG_INT_ENABLE    = 0x38;
const uint8_t REG_INT_STATUS    = 0x3A;
const uint8_t REG_ACCEL_XOUT_H  = 0x3B;

// =====================================================
// BLE settings - MUST match display code
// =====================================================
static BLEUUID serviceUUID("6f1c0001-4b1f-4f6c-9c79-1234567890ab");
static BLEUUID charUUID("6f1c0002-4b1f-4f6c-9c79-1234567890ab");

static BLEAdvertisedDevice* myDevice = nullptr;
static BLERemoteCharacteristic* pRemoteCharacteristic = nullptr;
static BLEClient* pClient = nullptr;

bool doConnect = false;
bool connected = false;
bool doScan = false;

// =====================================================
// Timing
// =====================================================
unsigned long lastSampleMs = 0;
unsigned long lastDebugMs = 0;
unsigned long lastThrowSentMs = 0;

const unsigned long sampleIntervalMs = 10;   // 100 Hz
const unsigned long debugIntervalMs  = 200;
const unsigned long minResendGapMs   = 1200;

unsigned long lastScanAttemptMs = 0;
const unsigned long SCAN_RETRY_MS = 3000;
bool isScanning = false;

// =====================================================
// Filtering
// =====================================================
const float ACC_LPF_ALPHA  = 0.25f;
const float GYRO_LPF_ALPHA = 0.25f;

float filtAccMag = 1.0f;
float filtGyroMag = 0.0f;

// =====================================================
// Throw detection parameters
// Tune these after testing
// =====================================================
const float THROW_START_ACC_G   = 0.70f;   // dynamic accel threshold
const float THROW_START_GYRO_DPS= 180.0f;  // gyro threshold
const float THROW_END_ACC_G     = 0.12f;   // end threshold
const float THROW_END_GYRO_DPS  = 70.0f;   // end threshold
const unsigned long THROW_END_HOLD_MS = 180;
const unsigned long MAX_THROW_MS      = 1200;
const unsigned long MIN_THROW_MS      = 80;
unsigned long throwCooldownUntilMs = 0;
const unsigned long THROW_COOLDOWN_MS = 500;

// =====================================================
// Final MPH gating
// =====================================================
const float MIN_SENDABLE_THROW_MPH = 10.0f;

// =====================================================
// Sensor data structure
// =====================================================
struct ImuSample {
  float ax_g;
  float ay_g;
  float az_g;
  float gx_dps;
  float gy_dps;
  float gz_dps;
  float accMag_g;
  float gyroMag_dps;
};

// =====================================================
// Throw feature state
// =====================================================
bool throwActive = false;
unsigned long throwStartMs = 0;
unsigned long throwQuietStartMs = 0;

float peakDynAcc_g = 0.0f;
float peakGyro_dps = 0.0f;
float accIntegral_gs = 0.0f;
float gyroIntegral_ds = 0.0f;

float lastComputedThrowMph = 0.0f;

// =====================================================
// Low-level I2C helpers
// =====================================================
bool writeReg(uint8_t addr, uint8_t reg, uint8_t value) {
  Wire.beginTransmission(addr);
  Wire.write(reg);
  Wire.write(value);
  return (Wire.endTransmission() == 0);
}

bool readReg(uint8_t addr, uint8_t reg, uint8_t &value) {
  Wire.beginTransmission(addr);
  Wire.write(reg);
  if (Wire.endTransmission(false) != 0) return false;

  if (Wire.requestFrom((int)addr, 1) != 1) return false;
  value = Wire.read();
  return true;
}

bool readBytes(uint8_t addr, uint8_t startReg, uint8_t *buf, size_t len) {
  Wire.beginTransmission(addr);
  Wire.write(startReg);
  if (Wire.endTransmission(false) != 0) return false;

  size_t got = Wire.requestFrom((int)addr, (int)len);
  if (got != len) return false;

  for (size_t i = 0; i < len; i++) {
    buf[i] = Wire.read();
  }
  return true;
}

int16_t makeInt16(uint8_t hi, uint8_t lo) {
  return (int16_t)((hi << 8) | lo);
}

bool probeAddress(uint8_t addr) {
  Wire.beginTransmission(addr);
  return (Wire.endTransmission() == 0);
}

// =====================================================
// MPU init
// =====================================================
bool initMPU6050() {
  uint8_t who = 0;

  if (!probeAddress(MPU_ADDR)) {
    Serial.println("No I2C response at 0x68");
    return false;
  }

  imuAddr = MPU_ADDR;

  Serial.print("MPU found at 0x");
  Serial.println(imuAddr, HEX);

  if (!readReg(imuAddr, REG_WHO_AM_I, who)) {
    Serial.println("Failed to read WHO_AM_I");
    return false;
  }

  Serial.print("WHO_AM_I = 0x");
  Serial.println(who, HEX);

  if (who != 0x68) {
    Serial.println("Unexpected WHO_AM_I");
    return false;
  }

  if (!writeReg(imuAddr, REG_PWR_MGMT_1, 0x00)) return false;
  delay(100);

  if (!writeReg(imuAddr, REG_SMPLRT_DIV, 0x09)) return false;
  if (!writeReg(imuAddr, REG_CONFIG, 0x03)) return false;
  if (!writeReg(imuAddr, REG_GYRO_CONFIG, 0x00)) return false;   // ±250 dps
  if (!writeReg(imuAddr, REG_ACCEL_CONFIG, 0x00)) return false;  // ±2g
  if (!writeReg(imuAddr, REG_INT_PIN_CFG, 0x00)) return false;
  if (!writeReg(imuAddr, REG_INT_ENABLE, 0x01)) return false;

  return true;
}

// =====================================================
// Read IMU
// =====================================================
bool readImu(ImuSample &s) {
  uint8_t buf[14];
  uint8_t intStatus = 0;

  if (!readReg(imuAddr, REG_INT_STATUS, intStatus)) return false;
  if (!readBytes(imuAddr, REG_ACCEL_XOUT_H, buf, 14)) return false;

  int16_t axRaw = makeInt16(buf[0],  buf[1]);
  int16_t ayRaw = makeInt16(buf[2],  buf[3]);
  int16_t azRaw = makeInt16(buf[4],  buf[5]);
  int16_t gxRaw = makeInt16(buf[8],  buf[9]);
  int16_t gyRaw = makeInt16(buf[10], buf[11]);
  int16_t gzRaw = makeInt16(buf[12], buf[13]);

  s.ax_g = axRaw / 16384.0f;
  s.ay_g = ayRaw / 16384.0f;
  s.az_g = azRaw / 16384.0f;

  s.gx_dps = gxRaw / 131.0f;
  s.gy_dps = gyRaw / 131.0f;
  s.gz_dps = gzRaw / 131.0f;

  s.accMag_g = sqrtf(s.ax_g * s.ax_g + s.ay_g * s.ay_g + s.az_g * s.az_g);
  s.gyroMag_dps = sqrtf(s.gx_dps * s.gx_dps + s.gy_dps * s.gy_dps + s.gz_dps * s.gz_dps);

  return true;
}
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

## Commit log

2026-01-27 Update print statement from 'Hello' to 'Goodbye'
2026-01-27 Revert "Update print statement from 'Hello' to 'Goodbye'"
    This reverts commit 0b9ea3a7ffee00b22fced410a536641664c64975.
2026-01-27 Update data flow diagram in README
    Replaced link to PDF with an image of the schematic.
2026-01-29 Added project files and screenshots to github for Lab3
    [Lab3.kicad_pcb, Lab3.kicad_sch]
2026-01-30 Added Manufacturing FIles (Gerber and Drill)
    Although there are no drill holes in this diagram
    [Lab3-B_Cu.gbr, Lab3-B_Mask.gbr, Lab3-B_Paste.gbr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]
2026-02-02 Added final personal PCB files
    Excluding PCB files for Gerber and actual Manufacturing.
    [514-Schematic.kicad_pcb, 514-Schematic.kicad_sch, Lab3.kicad_pcb]
2026-02-08 Create Battery Estimate.pdf
2026-03-02 Add PCB and Code for Devices
    [514-Schematic-B_Cu.gbr, 514-Schematic-B_Mask.gbr, 514-Schematic-B_Paste.gbr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]
2026-03-15 Added updated code for both Sensing and Display Device
